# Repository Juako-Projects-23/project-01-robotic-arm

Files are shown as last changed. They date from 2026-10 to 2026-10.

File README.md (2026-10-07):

 5-DOF 3D-Printed Robotic Arm (6-Axis Control)

> **End-to-end design, 3D printing, and C++ programming of a functional 5-DOF robotic arm using an Arduino Mega 2560.**

 **[Click here to view/download the full Engineering Portfolio Presentation (PDF)](ROBOTIC-ARM-PROJECT.pdf)**

 Overview
This repository contains the source code, 3D models, and media for a custom-built mechatronic system. For a detailed breakdown of the engineering process, thermal deformation solutions, custom power management, and deadband signal filtering, please refer to the comprehensive PDF presentation linked above.

  Repository Structure
*   `/src` - Arduino C++ source code (`.ino`) for kinematics and joystick mapping.
*   `/cad` - `.stl` files and 3D models ready for printing.
*   `/media` - Demonstration video
*   `ROBOTIC-ARM-PROJECT.pdf` - Detailed project documentation and technical challenges solved.

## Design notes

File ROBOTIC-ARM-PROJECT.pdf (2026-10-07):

# 5-DOF 3D-Printed Robotic Arm (6-Axis Control)

Role: Mechatronics Engineering (Assembly, Power Management, C++ Programming)
Tech Stack: Arduino Mega 2560, OrcaSlicer, 3D Printing (PLA), C++

## CHALLENGE AND OBJECTIVE

The goal of this project was to bridge the gap between software code and physical mechanics by building a functional robotic arm. It served as a hands-on introduction to 3D printing workflows, mechanical tolerances, and embedded control systems.

## ARCHITECTURE AND HARDWARE

Electronic Components:

Microcontroller: Arduino Mega 2560

Actuators: 1x 28BYJ-48 (5V Stepper motor for precise base rotation) & 4x SG90 Micro Servomotors

Power Supply: Custom-adapted 12A-5V external power supply

Control Interface: 2x Analog Joysticks

Wiring: 3x Terminal blocks (clemas)

Materials and Software:

Software: Arduino IDE, OrcaSlicer

Manufacturing: Black Basic PLA, standard mounting screws

3D Model: Sourced from Printables.com, adapted for the specific motors used.

## ENGINEERING PROCESS

Sin título | 1

### 1. 3D Printing and Manufacturing

The models were sliced using OrcaSlicer. During initial manufacturing, thermal warping became a significant issue.

Solution: I optimized the printing workflow by dividing the components into smaller batches. This prevented rapid, uneven cooling between layers, completely eliminating the warping issue.

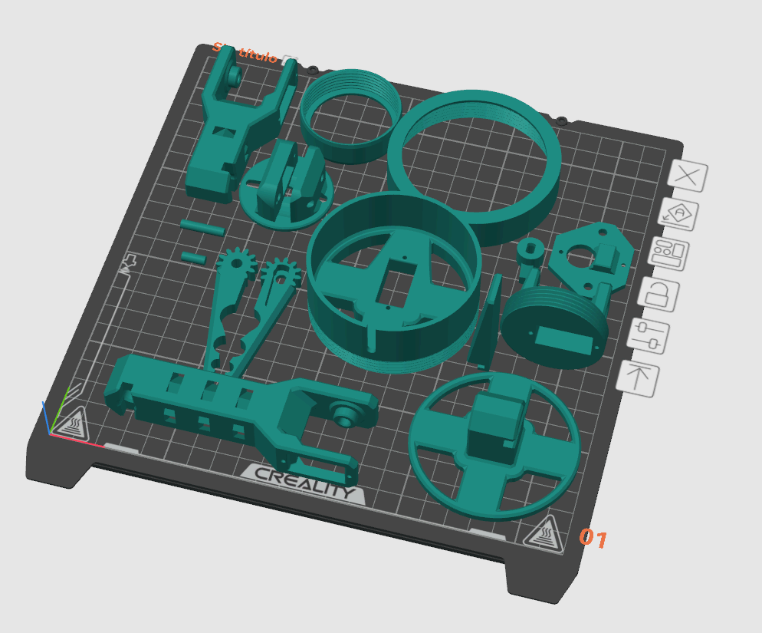
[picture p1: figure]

### 2. Circuit Design and Power Distribution

The most critical hardware challenge was powering the servomotors, which draw high peak amperage at 5V.

Solution: Instead of buying a new module, I repurposed an unused 12A-5V barrel-jack power supply. I stripped the protective casing and adapted the raw wiring into terminal connector blocks. This provided a massive safety margin for the current draw while successfully recycling existing hardware.

### 3. Programming and Control

The control logic was written in C++ via the Arduino IDE. The system uses continuous angle mapping, incrementally adding or subtracting degrees from the servos' current position based on the joystick input.

## TECHNICAL CHALLENGES & SOLUTIONS

Mechanical Tolerances (Thermal Deformation):
Once printed, the servo cavities were too tight due to material expansion. Instead of reprinting, I applied targeted heat to the cavity edges to slightly soften the PLA. I then press-fit the servos, allowing the plastic to cool and harden around them for a perfectly rigid, custom fit

Noisy Analog Signals (Deadband Implementation):
The analog joysticks fluctuated by ±50 units on the 0-1023 analog scale, causing severe servo jitter. I implemented a software deadband (e.g., ignoring readings between 350 and 750) to filter out the baseline noise. This ensured the motors only moved upon deliberate joystick actuation.

Servo Gearbox Failure:
During testing, internal gears inside one of the SG90 servos dislodged. I manually unscrewed the micro-servo casing, extracted the gear train, and carefully realigned each gear to its correct position, fully restoring the motor's functionality.

## DEMONSTRATION AND RESULTS

The robotic arm successfully lifts a maximum payload of approximately 50 grams (in addition to its own structural weight). The movement is fluid, responsive, and operates with minimal vibration.

Future Roadmap:

Integration of a camera module for computer vision and object recognition.

Scaling up the project using high-torque metal-gear servos for heavy-duty applications.

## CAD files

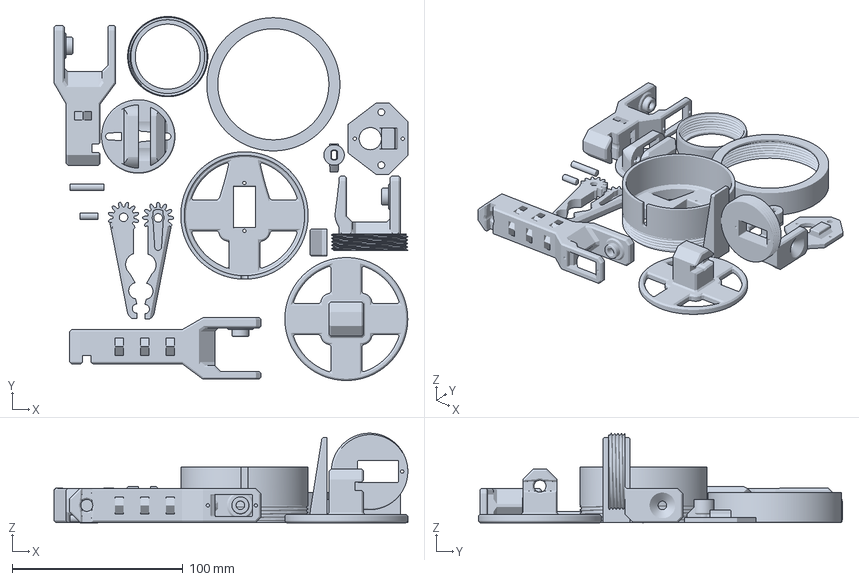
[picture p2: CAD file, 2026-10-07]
ROBOTIC-ARM-3D-PRINTING.3mf
207.2 x 213.2 x 52.5 mm

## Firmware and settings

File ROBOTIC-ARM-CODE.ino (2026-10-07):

#include <Servo.h>
#include <Stepper.h>


Servo miServo; 
Stepper miStepper(2048,8,10,9,11);
Servo miServo2;
Servo miServo3;
Servo miServo4;

int pinJoystickX = A0;
int pinJoystickY = A2;
int pinJoystickX2 = A15;
int pinJoystickY2 = A14;
int angulo = 90; 
int angulo2 = 90;
int angulo3 = 90;
int angulo4 = 90;
int step=0;
int pinBotonAbrir = 12;  
int pinBotonCerrar = 13; 

void setup() {
  Serial.begin(9600);
  
  miServo.attach(6); 
  miServo2.attach(4);
  miServo3.attach(2);
  miServo4.attach(3);
  miStepper.setSpeed(5);
  pinMode(pinBotonAbrir, INPUT_PULLUP);
  pinMode(pinBotonCerrar, INPUT_PULLUP);
}

void loop() {
  int posicionX = analogRead(pinJoystickX);
  int posicionY = analogRead(pinJoystickY);
  int posicionX2 = analogRead(pinJoystickX2);
  int posicionY2 = analogRead(pinJoystickY2);
  Serial.print('EJE X' );
  Serial.println(posicionX);
  Serial.print('EJE Y' );
  Serial.println(posicionY);
  


  
  if (posicionX < 300) {
    angulo = angulo + 1;
    if (angulo > 180) angulo = 180; 
    miServo.write(angulo);
  }

  
  if (posicionX > 800) {
    angulo = angulo - 1;
    if (angulo < 0) angulo = 0; 
    miServo.write(angulo);
  }

 if (posicionX2 < 300) {
    angulo2 = angulo2 + 1;
    if (angulo2 > 180) angulo2 = 180; 
    miServo2.write(angulo2);
  }

  
  if (posicionX2 > 800) {
    angulo2 = angulo2 - 1;
    if (angulo2 < 0) angulo2 = 0; 
    miServo2.write(angulo2);
  }

  if (posicionY2 > 800) {
    angulo3 = angulo3 + 1;
    if (angulo3 > 180) angulo3 = 180; 
    miServo3.write(angulo3);
  }

  
  if (posicionY2 < 300) {
    angulo3 = angulo3 - 1;
    if (angulo3 < 0) angulo3 = 0; 
    miServo3.write(angulo3);
  }

  if (posicionY > 800){

    miStepper.step(20);

  }

  if (posicionY < 300){

    miStepper.step(-20);
    
  }

 
  if (digitalRead(pinBotonAbrir) == LOW) { 
    angulo4 = angulo4 + 2; 
    if (angulo4 > 180) angulo4 = 180; 
    miServo4.write(angulo4);
  }
  
  // Si pulsas el segundo joystick
  if (digitalRead(pinBotonCerrar) == LOW) { 
    angulo4 = angulo4 - 2;
    if (angulo4 < 0) angulo4 = 0; 
    miServo4.write(angulo4);
  }



 

  delay(20); 
}
